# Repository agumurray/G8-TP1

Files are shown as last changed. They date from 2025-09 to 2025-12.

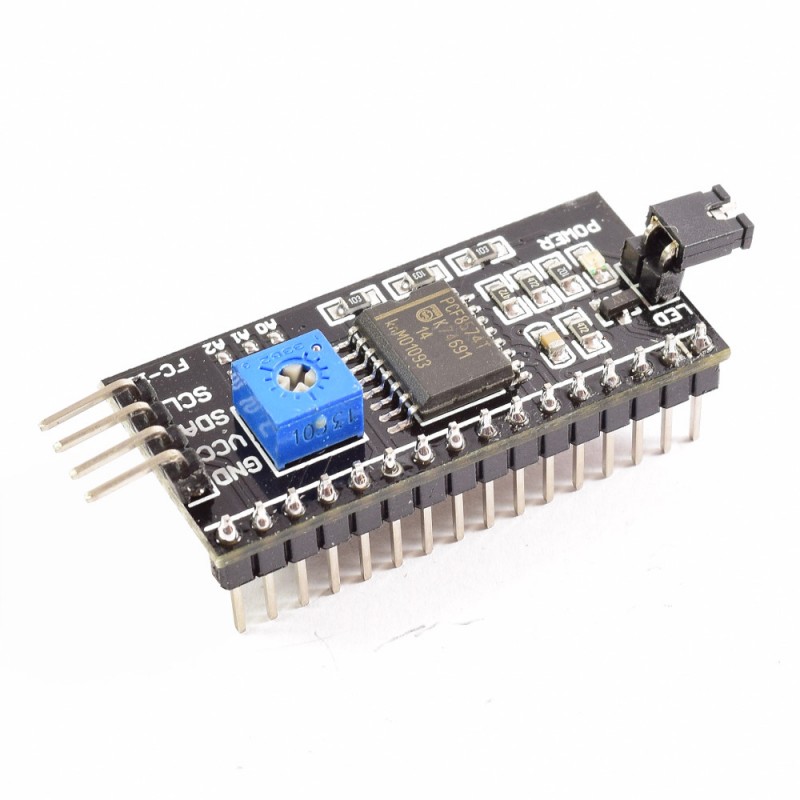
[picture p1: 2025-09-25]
firmware_v3/test/test_hcsr04/sapi/lcd/lcd_i2c/I2C expander PCF8574/modulo-adaptador-lcd-a-i2c_PCF8574.jpg

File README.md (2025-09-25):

# TdP-Grupo8-2025

**Robot resolutor de laberintos con EDU-CIAA**

Este proyecto consiste en el diseño y construcción de un robot móvil capaz de resolver laberintos físicos con paredes de manera autónoma. El sistema utiliza como controlador principal la **EDU-CIAA**, que gestiona los sensores y motores, y ejecuta algoritmos de navegación para alcanzar la salida sin necesidad de un mapa previo.

## Características principales

* Exploración autónoma de laberintos físicos.
* Algoritmos de resolución basados en estrategias clásicas (wall-following, Pledge, Trémaux).
* Plataforma móvil con dos motores DC controlados mediante un puente H L298N.
* Sensores ultrasónicos para la detección de paredes y obstáculos.
* Posibilidad de extender funcionalidades con:

  * Telemetría mediante ESP32 e interfaz web.
  * Algoritmos de búsqueda óptima (Flood Fill, A*).
  * Sensores adicionales como giroscopio para corrección de trayectoria.

## Tecnologías utilizadas

* **Hardware:**

  * EDU-CIAA (controlador central).
  * Motores DC con puente H L298N.
  * Sensores ultrasónicos HC-SR04.
  * Batería y sistema de alimentación dedicado.
  * (Opcional) ESP32 para telemetría y giroscopio.

* **Software:**

  * Lenguaje C para firmware en la EDU-CIAA.
  * Algoritmos de filtrado de señales y resolución de laberintos.
  * (Opcional) HTML/CSS/JavaScript para interfaz web de monitoreo.

## Objetivos

* **General:** Desarrollar un robot controlado por EDU-CIAA capaz de explorar físicamente un laberinto con paredes y alcanzar la salida mediante estrategias de navegación autónoma.

* **Primarios:**

  1. Diseñar la plataforma mecánica y de potencia (chasis, ruedas, transmisión, alimentación).
  2. Integrar sensado frontal para detección de paredes/obstáculos.
  3. Implementar un algoritmo de resolución de laberintos con información local.
  4. Validar el funcionamiento en laberintos de prueba con métricas definidas.

* **Secundarios:**

  1. Incorporar una interfaz web para recolectar telemetría.
  2. Implementar algoritmos de búsqueda óptima.
  3. Integrar un sensor giroscópico para corrección de maniobras.

## Integrantes

Este proyecto fue desarrollado por el **Grupo 8** en el marco de la materia **Taller de Proyecto I** en la Facultad de Ingeniería de la UNLP:

* Cabral Ramiro Nicolas
* Murray Agustín
* González Juan
* Mendoza Tomás

---

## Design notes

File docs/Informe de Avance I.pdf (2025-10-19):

Informe de Avance I - Taller de Proyecto I

Robot resolutor de laberintos con EDU-CIAA

Grupo 8

Cabral Ramiro, Murray Agustin, Gonzalez Juan, Mendoza Tomas

Facultad de Ingeniería - UNLP

Introducción

El presente proyecto tiene como objetivo el desarrollo de un robot móvil autónomo capaz de

resolver laberintos. El sistema se basa en la placa de desarrollo EDU-CIAA-NXP, la cual

cumple el rol de unidad de control central. El robot se desplazará mediante dos motores de

corriente continua controlados a través de un puente H L298N, y contará con tres sensores

ultrasónicos HC-SR04 para la detección de obstáculos.

El algoritmo principal de navegación estará orientado a la resolución de laberintos, utilizando

estrategias como el “Wall Follower” o variantes más avanzadas. Como objetivo secundario, se

busca que el robot pueda comunicar información a la PC vía UART, lo que permitirá un

monitoreo en tiempo real y facilitará las tareas de depuración.

Este proyecto representa una oportunidad para aplicar conocimientos adquiridos en control,

programación embebida, electrónica digital y analógica, así como en integración de sistemas.

Objetivos del proyecto

Objetivos principales

- Diseñar la plataforma mecánica y de potencia (chasis, ruedas, alimentación) adecuada

para pruebas en laberintos.

- Integrar sensores ultrasónicos para detección de obstáculos y paredes.
- Implementar un algoritmo de resolución de laberintos autónomo (p. ej. Wall Follower).
- Implementar rutinas de control de motores basadas en tracción diferencial (PWM +

puente H).

- Establecer protocolos de prueba y métricas de éxito.

Objetivos secundarios

- Implementar comunicación UART con PC para telemetría
- Evaluar la incorporación de algoritmos más complejos (Flood Fill, A*).
- Analizar la posibilidad de integrar sensores adicionales (ej. giroscopio).

Análisis de requerimientos

Requerimientos funcionales - Hardware

- El sistema debe usar la EDU-CIAA como controlador central.
- El robot debe disponer de dos motores DC controlados por un driver L298N, capaces de

ejecutar avance, retroceso y giros en el lugar.

- Debe incluir tres sensores ultrasónicos HC-SR04 (1 frontal, 2 laterales).
- Fuente de alimentación autónoma con batería recargable de 7.4 V.
- Regulación de nivel lógico en señales de entrada (ECHO de sensores: de 5 V a 3.3 V).

Requerimientos funcionales - Software

- Lectura confiable de los sensores ultrasónicos y conversión a distancia en cm.
- Filtrado de ruido en lecturas (media móvil).
- Rutinas de movimiento: avance recto, giro en sitio, retroceso y parada.
- Algoritmo de resolución de laberintos (mínimo Wall Follower).
- Comunicación UART con PC para debug.

Requerimientos no funcionales

- Código modular, documentado y versionado en Git.
- Seguridad eléctrica mínima: protección contra inversión de polaridad, separación de

alimentación motores/lógica.

- Facilidad de prueba: modos de calibración de sensores y motores.
- Cumplir con los hitos de entrega fijados por la cátedra:
- Informe de Avance I: 2 de Octubre de 2025.
- Informe de Avance II: 3 de Noviembre de 2025
- Informe final: 18 de diciembre de 2025

Diseño de hardware

Componentes principales

- EDU-CIAA-NXP: placa de desarrollo basada en el microcontrolador ARM Cortex-M4

LPC4337. Permite gestionar periféricos, manejar interrupciones y ejecutar el algoritmo

de resolución.

- Sensores ultrasónicos HC-SR04 (x3): permiten medir distancias en distintas direcciones

(frontal y laterales). Operan con señal de disparo (Trigger) y eco (Echo).

- Driver de motores L298N: puente H doble que permite controlar la velocidad y sentido

de giro de dos motores DC.

- Motores DC (x2): utilizados para la tracción diferencial. Su control se logra mediante

PWM aplicado al L298N.

- Batería 18650 Li-ion 2600 mAh (x2): fuente de energía principal del sistema. Permite

portabilidad y autonomía suficiente para pruebas de campo.

- Divisores resistivos: Se utilizaran para llevar las señales ECHO de los sensores de 5V a

3.3V, que es el nivel que soportan las entradas de la placa.

- Estructura mecánica: chasis liviano con dos ruedas motrices y una rueda loca

estabilizadora.

Interfaces eléctricas

Elemento | Tension de operacion | Corriente típica | Corriente máxima
EDU-CIAA-NXP | 5V | 150mA | 300mA
HC-SR04 | 5V | 15mA | 30mA
L298N (control) | 5V | 20mA | 50mA
Motor DC | 7.4V | 300mA | 1A

Para el correcto funcionamiento del sistema se seleccionó como fuente de alimentación dos

baterías recargables 18650 de 3.7 V y 2600 mAh conectadas en serie, lo que proporciona una

tensión nominal de 7.4 V y un máximo de 8.4 V al estar completamente cargadas. Esta elección

permite disponer de una fuente portátil, liviana y con suficiente capacidad energética para

sostener el funcionamiento del robot durante las pruebas.

Los cálculos de consumo realizados muestran que, en condiciones típicas de operación, el

sistema demanda aproximadamente 0.77 A desde la batería, lo que se traduce en una autonomía

teórica de alrededor de 3.3 horas. Considerando pérdidas, variaciones en la eficiencia y picos de corriente de arranque, se estima una duración práctica de entre 2.8 y 3.2 horas, lo cual resulta

adecuado para el uso en un prototipo experimental.

En situaciones de arranque o bloqueo de los motores, el consumo puede alcanzar picos cercanos

a 2.2 A, reduciendo la autonomía a aproximadamente 1.2 horas si esta condición extrema se

mantuviera de forma continua. Sin embargo, en la práctica estos picos son breves y no

comprometen la estabilidad general del sistema.

El driver L298N introduce una caída de tensión de aproximadamente 2 V en los canales de

potencia, lo que implica cierta disipación térmica. Por esta razón, se recomienda el uso de un

pequeño disipador en el integrado y evitar condiciones de motor bloqueado por tiempos

prolongados. Aun así, el componente resulta suficiente para manejar los dos motores DC del

chasis en la etapa de desarrollo.

El mismo módulo L298N dispone de una salida regulada de 5 V, la cual se utiliza para alimentar

directamente la placa EDU-CIAA y los sensores ultrasónicos. De este modo, se simplifica la

distribución de energía y se evita la necesidad de un regulador adicional.

Finalmente, las señales de retorno ECHO de los sensores HC-SR04 requieren adaptación de

nivel, dado que la EDU-CIAA admite un máximo de 3.3 V en sus entradas. Para ello se

implementan divisores resistivos formados por una resistencia de 10 kΩ (conectada a la salida

ECHO) y otra de 20 kΩ a masa. El cálculo de la tensión de salida es:

V | , donde | , | y
in = V
out

·

R2
R1 + R2 | V

in = 5V R1 = 10 kΩ R2 = 20 kΩ

Entonces, V
out ≃ 3. 33V

Lista de materiales (BOM con precios ML)

Componente | Cant. | Precio unitario (ARS) | Total (ARS)
EDU-CIAA-NXP | 1 | 90.000 | 90.000
HC-SR04 | 3 | 3.500 | 10.500
L298N | 1 | 5.500 | 5.500
Kit auto arduino (incluye chasis, ruedas y motores) | 1 | 25.000 | 25.000
Baterías 18650 Motoma 2600 mAh | 2 | 3.000 | 6.000
Misceláneos (cables, divisores resistivos, soportes) | - | 5.000 | 5.000

Circuito esquemático

En la siguiente figura se presenta el diseño esquemático en KiCad, donde se observa la

interconexión entre la EDU-CIAA, los tres sensores ultrasónicos, el driver de motores L298N y

los motores DC.

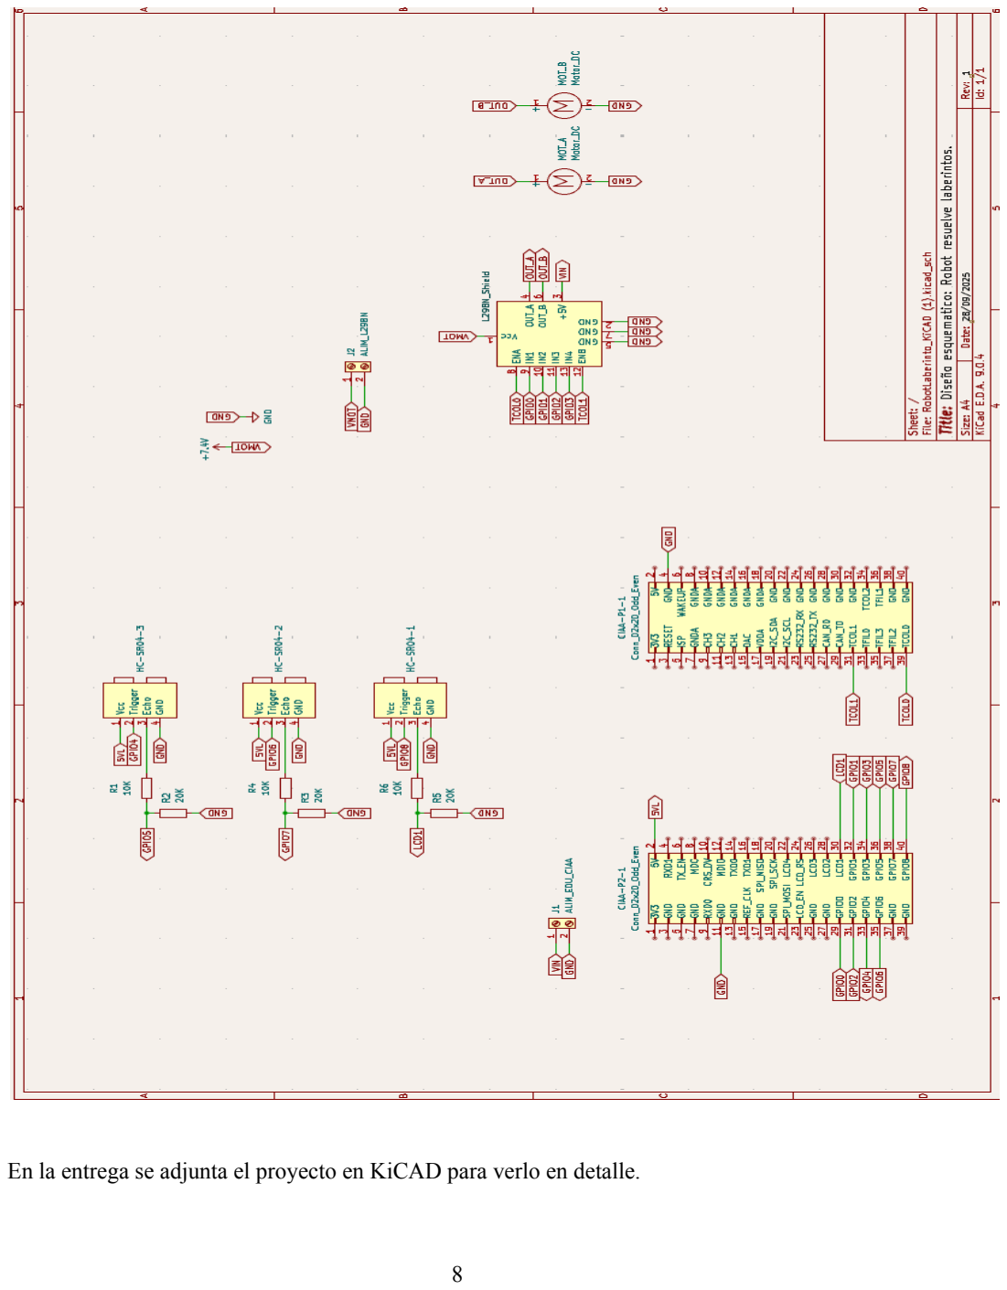
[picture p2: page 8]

En la entrega se adjunta el proyecto en KiCAD para verlo en detalle.

Diseño del firmware

El desarrollo del firmware para el robot resolutor de laberintos se plantea bajo una arquitectura

modular, con separación en capas bien definidas, lo que permitirá mayor claridad en el

mantenimiento y la depuración del sistema. La EDU-CIAA-NXP, basada en el microcontrolador

LPC4337, será la encargada de ejecutar todas las rutinas de control, sensado y comunicación.

Arquitectura del firmware

El firmware se organiza en tres capas principales:

1. Capa de Drivers (Bajo nivel):
- Configuración de periféricos básicos de la EDU-CIAA (GPIO, PWM, UART,

timers).

- Rutinas para el disparo y lectura de los sensores ultrasónicos HC-SR04.
- Control de las señales de entrada al L298N (Enable y direccionales).
- Conversión de las lecturas de tiempo de vuelo a distancia en centímetros.
2. Capa Intermedia (Middleware / Librerías):

- Implementación de rutinas de filtrado de señales (ej. media móvil de N muestras)

para minimizar errores en las lecturas ultrasónicas.

- Módulos de control de movimiento de alto nivel: avance, retroceso, giro a

derecha, giro a izquierda, detener.

- Gestión de comunicación UART (envío de telemetría y recepción de comandos de

prueba desde PC).

3. Capa de Aplicación (Algoritmo de navegación):
- Implementación del algoritmo Wall Follower como solución mínima para la

resolución del laberinto.

- Integración de las decisiones del algoritmo con las rutinas de movimiento.
- Generación de información de estado y eventos enviados a la PC para depuración.

Este diseño modular permitirá que futuros cambios en sensores, drivers o algoritmos no afecten

la totalidad del sistema.

Esquema de funcionamiento

El ciclo principal del programa está basado en un bucle infinito con atención periódica a

interrupciones de temporizadores.

- Los temporizadores gestionan la generación de señales PWM para los motores.
- Una interrupción periódica se encarga de iniciar las mediciones ultrasónicas de forma

secuencial (disparando cada sensor en turnos).

- El bucle principal lee los resultados procesados, aplica el algoritmo de decisión y

actualiza el estado de los motores.

- Paralelamente, se ejecutan rutinas de transmisión UART para enviar los datos a la PC.

Diagrama de flujo simplificado:

1. Inicializar periféricos (PWM, GPIO, UART, timers).
2. Iniciar medición de sensores ultrasónicos en forma cíclica.
3. Filtrar y almacenar las lecturas de distancia.

4. Evaluar condiciones del laberinto según el algoritmo Wall Follower:
- Si hay camino libre al frente, avanzar.
- Si hay pared a la izquierda, continuar recto.
- Si no hay pared a la izquierda, girar en esa dirección.
- Si la trayectoria está bloqueada, girar a la derecha o retroceder.
5. Enviar datos de estado y distancias por UART.
6. Repetir.

Cronograma

Link al cronograma. (https://docs.google.com/spreadsheets/d/1fumWjYeI3rMNOMrfwoXf-empmanw7tX2/edit?gid=771373370)

División de tareas

Juan | Ramiro | Agustin | Tomas
Algoritmo de movimiento del robot (avanzar, girar) | Algoritmo de resolución de laberintos | Armado del circuito de alimentación e interconexión | Montaje del equipo
Armado de laberintos | Diseño del circuito esquemático en KiCAD | Lógica de sensado | Diseño del circuito esquemático en KiCAD
| Integración de esp32 para telemetría (secundario) | Integración de giroscopio (secundario) | Algoritmo de recolección de datos (secundario

Bibliografía

- Proyecto CIAA: https://www.proyecto-ciaa.com.ar/
- HC-SR04 datasheet: https://cdn.sparkfun.com/datasheets/Sensors/Proximity/HCSR04.pdf
- L298N datasheet:

https://drive.google.com/drive/u/0/folders/1ENpeQHSaa5TVw6c3gilW9JXR4ox_CZ4J

- Algoritmos de resolución de laberintos:

https://en.wikipedia.org/wiki/Maze-solving_algorithm

- KiCAD EDA: https://www.kicad.org/

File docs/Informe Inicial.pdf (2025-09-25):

Informe Inicial - Taller de Proyecto I

Robot resolutor de laberintos con EDU-CIAA

Grupo 8

Cabral Ramiro, Murray Agustin, Gonzalez Juan, Mendoza Tomas

Facultad de Ingeniería - UNLP

Introducción

Este proyecto propone diseñar y construir un robot móvil que resuelve laberintos físicos con

paredes utilizando como controlador principal la EDU-CIAA (plataforma educativa basada en la

familia CIAA). La elección de EDU-CIAA está fijada por la cátedra y orienta la implementación

del firmware y el acceso a E/S y periféricos. [1]

El objetivo en esta etapa inicial es definir el alcance físico y funcional del prototipo mínimo

viable y los criterios de validación. La intención es comenzar con una plataforma de tracción

simple, sensado para detección de paredes, y un algoritmo que permita al robot, con información

local (sin mapa previo), encontrar la salida del laberinto; en una segunda fase se podrá evaluar la

inclusión de telemetría y una interfaz móvil/web para registro y visualización de estadísticas.

Objetivos

Objetivo general: Desarrollar un robot, controlado por la EDU-CIAA, capaz de explorar

físicamente un laberinto con paredes y alcanzar la salida mediante estrategias de navegación

autónoma.

- Objetivos primarios:
1. Diseñar la plataforma mecánica y de potencia (chasis, ruedas, transmisión,

alimentación) adecuada para pruebas en un laberinto con paredes.

2. Integrar sensado frontal para detección de paredes/obstáculos y un módulo de

control que permita maniobrar (avanzar, girar, detener).

3. Implementar un algoritmo de resolución de laberintos apropiado para operar con

información local (p.ej. wall-following, Pledge o Trémaux) y validar su

funcionamiento en al menos un conjunto de laberintos de prueba. [2]

4. Definir protocolos de prueba, métricas de éxito y documentación mínima para

replicar los ensayos.

- Objetivos secundarios:
1. Implementar una interfaz web para recolectar telemetría y análisis del

funcionamiento del robot, utilizando un microcontrolador como el ESP-32 o

similar.

2. Implementar un algoritmo de búsqueda óptima para la resolución del laberinto,

como el Flood Fill o el A*.

3. Incorporar un sensor giroscópico que proporcione mediciones de orientación y

rotación angular, con el objetivo de corregir desviaciones durante las maniobras.

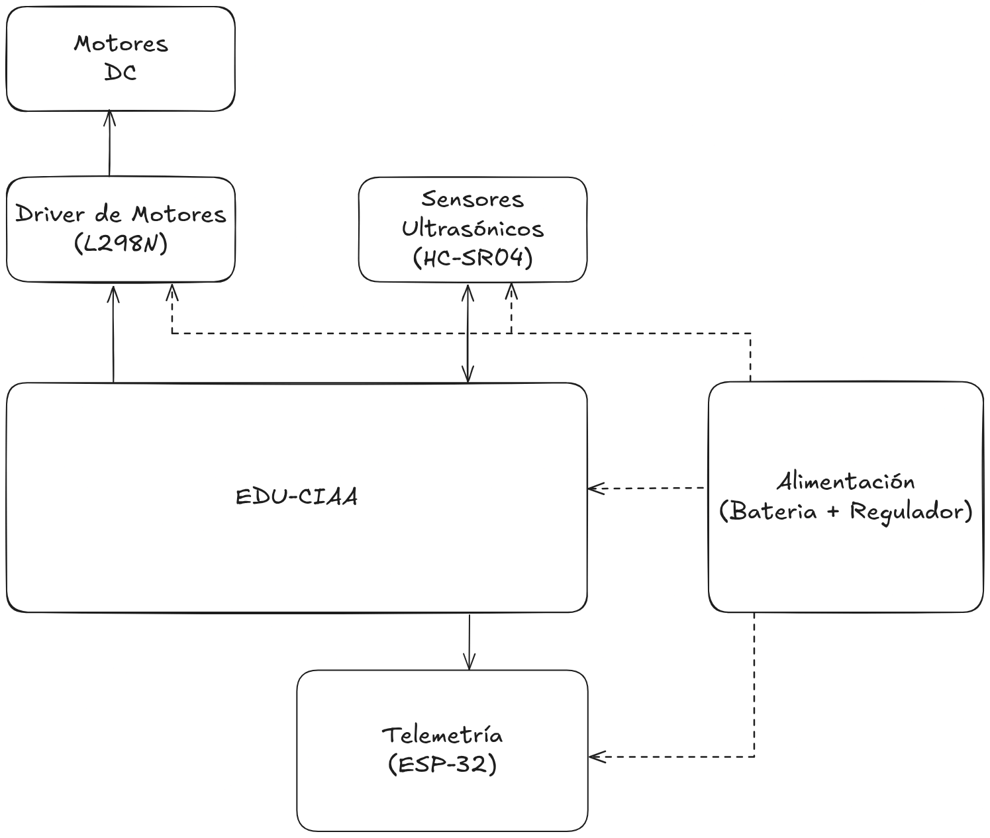
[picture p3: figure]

Figura 1: Diagrama en bloques.

En la Fig. 1 se presenta el diagrama en bloques del robot, el cual consiste de la EDU-CIAA, la

cual recolecta datos de los sensores ultrasónicos, y en base a los datos recolectados y según un

algoritmo de resolución, acciona los motores para poder mover al robot. Los dos motores

utilizados son accionados mediante un Puente-H L298N. Adicionalmente, según lo aclarado en

los objetivos secundarios, eventualmente se puede incorporar un microcontrolador como el

ESP-32 o similar con el fin de recolectar telemetría y presentar información en una interfaz web.

Análisis de requerimientos

- Requerimientos funcionales - Hardware
1. El sistema debe usar la EDU-CIAA como controlador central (E/S digitales,

temporizadores, ADC, UART, entre otros).

2. El robot tendrá una plataforma con varias ruedas y al menos dos actuadores

(configuración a definir) capaz de controlar avance y giros.

3. Disponer de uno o más sensores de distancia/proximidad (basados en tiempo de

vuelo acústico o equivalente) ubicados en la parte frontal y, opcionalmente,

laterales, para detectar paredes.

4. Fuente de alimentación apropiada para electrónica y motores, con separación y

protecciones razonables.

- Requerimientos funcionales - Software
1. Lectura fiable de los sensores de distancia y conversión a unidades físicas (cm o
m) usando la relación tiempo-velocidad del sonido (Time-of-Flight). [3]
2. Filtrado básico de las lecturas (p.ej. media móvil o mediana) para reducir ruido y

rechazar lecturas aberrantes.

3. Rutinas de movimiento: avance controlado, giro en el lugar (90° u otros ángulos

definidos) y parada segura.

4. Algoritmo de toma de decisiones para resolver el laberinto.
- Requerimientos no funcionales
1. Código modular y documentado; control de versiones.

2. Seguridad eléctrica mínima: separación de fuentes, protección contra inversión de

polaridad y cortes seguros en caso de fallo.

3. Facilidad de pruebas: puntos de prueba para sensores y actuadores, y modo

“calibración” para ajustar parámetros.

Cronograma preliminar

Se adjunta el link: Cronograma.xlsx (https://docs.google.com/spreadsheets/d/1fumWjYeI3rMNOMrfwoXf-empmanw7tX2/edit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)

División de tareas del grupo

Se realiza una primera división estimativa. La misma está sujeta a cambios ya que durante el

proceso de desarrollo, es posible que aparezcan nuevos problemas y/o retos a resolver.

Juan | Ramiro | Agustin | Tomas
Algoritmo de movimiento del robot (avanzar, girar) | Algoritmo de resolución de laberintos | Armado del circuito de alimentación e interconexión | Montaje del equipo
Armado de laberintos | Integración de esp32 para telemetría (secundario) | Lógica de sensado | Algoritmo de recolección de datos (secundario)
| | Integración de giroscopio (secundario)

Bibliografía

1. Proyecto CIAA (https://www.proyecto-ciaa.com.ar/index_comprar_educiaanxp_en.html)
2. Algoritmo de resolución de laberintos (https://en.wikipedia.org/wiki/Maze-solving_algorithm)

3. Funcionamiento de sensores ultrasonido (https://www.ti.com/lit/pdf/slaa907)

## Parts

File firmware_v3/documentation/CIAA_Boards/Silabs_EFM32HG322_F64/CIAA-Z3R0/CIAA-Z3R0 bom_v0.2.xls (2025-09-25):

Reference | Quantity | Value | Footprint | Part number | digikey part number
C12 | 1 | 4.7u | Capacitor 0603 | CC0603KRX5R7BB475 | 311-1785-1-ND
C2 C3 C4 C5 C6 | 5 | 100n | Capacitor 0603 | CC0603KRX7R7BB104 | 311-1088-1-ND
C8 | 1 | 10u | Capacitor 0603 | GRM188R61C106KAALD | 490-10728-1-ND
C1 C10 C11 C7 C9 | 5 | 1u | Capacitor 0603 | CC0603KRX7R7BB105 | 311-1446-1-ND
D1 D3 | 2 | LED GREEN | LED 0805 | LTST-C170GKT | 160-1179-1-ND
D2 | 1 | PMEG2005CT | SOT-23-3 | PMEG2005CT,215 | 1727-5188-1-ND
D4 | 1 | SD0603S040S0R2 | Diode 0603 | SD0603S040S0R2 | 478-7798-1-ND
U1 | 1 | EFM32HG-48LQFP | LQFP-48 7x7mm Pitch 0.5mm | EFM32HG322F64G-B-QFP48 | 336-3835-ND
U2 | 1 | SPX3819M5-L-3-3 | SOT-23-5 | SPX3819M5-L-3-3/TR | 1016-1873-1-ND
U3 | 1 | USBLC6-2 | SOT-23-6 | USBLC6-2SC6 | 497-5235-1-ND
SW1 SW2 | 2 | Switch EVQ-PE105K | Switch SPST-NO 6mm x 3.5mm | EVQ-PE105K | P13594SCT-ND
J3 | 1 | USB Micro-B | USB_Micro-B_Molex_47346-0001 | Molex 473460001 | WM17141CT-ND
J4 | 1 | Header SMD 2x2 Pitch 2.54mm | Pin Header 2x2 Pitch 2.54mm SMD | M20-8760242 | 952-3254-ND
R1 R2 | 2 | 15R | Resistor 0603 | RC0603JR-0715RL | 311-15GRCT-ND
R3 R4 R5 R6 | 4 | 1K | Resistor 0603 | RC0603JR-0710KL | 311-10KGRCT-ND

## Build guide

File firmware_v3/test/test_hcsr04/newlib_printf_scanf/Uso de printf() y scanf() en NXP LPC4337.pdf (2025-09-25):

# Uso de printf() y scanf() en el microcontrolador NXP LPC4337

# Biblioteca newlib, printf() y scanf() completas o reducidas

La biblioteca estándar de C llamada newlib, que incluye el compilador arm-none-eabi del NXP LPC4337 (el microcontrolador que tiene al EDU-CIAA-NXP o la CIAA-NXP) permite utilizar printf() y scanf() con el microcontrolador.

La biblioteca newlib permite ser compilada en 2 versiones. Una versión completa y una versión reducida nombrada newlib nano.

Si se utiliza newlib nano printf() y scanf() no permiten imprimir o recibir valores en punto flotante (float).

Para desactivar newlib nano y que compila la new lib completa en la carpeta app del proyecto, el archivo config.mk poner:

USE_NANO=n

Por defecto viene en y (que si use nano).

De esta manera podemos poner en un programa:

printf( "Pi vale aproximadamente %f\n", 3.14 );

scanf() y printf() utilizan la UART2 del microcontrolador (UART_USB en la sAPI) como entrada/salida estándar por lo que no se debería reconfigurar la UART2, la está configurada por defecto a 115200 baudios. Esto se hace en el startup del microcontroaldor.

Entonces un programa básico que utilice printf() puede ser simplemente:

#include "sapi.h" // <= Biblioteca sAPI, o alternativamente puede

| // usarse board.h que incluye LPCOpen
int main( void )
{
printf( "Pi vale aproximadamente %f\n", 3.14 ); while( TRUE );
return 0;
}

NOTA:

Si usan printf() en un microcontrolador van a notar que no imprime directamente (envía directo a la UART) si no que lo hace a través de un buffer el cual se envía a la salida estándar, en nuestro caso la UART.

En un programa en la PC si no hay \n este buffer se envía a la salida estándar cuando se llama a la función fflush(), la cual por ejemplo se llama cuando termina el programa.

En embebidos el programa no termina nunca (por el while(1)), entonces hay que forzar el fflush de 2 formas:

1. Llamando a la función fflush():

fflush(stdout);

2. Con \n dentro del texto de printf()

printf( "Hola\n" );

# Uso de memorias del microcontrolador

Se puede probar compilar el mismo programa con la opción USE_NANO en "y" y también en "n" y observar la diferencia de ocupación de memorias.

### Con newlib nano

text | data | bss | dec | hex filename
11460 | 300 | 76 | 11836 | 2e3c app/out/app.elf

En este caso printf() no imprime los valores float %f, pero no da errores, simplemente los ignora.

### Con newlib completa

text | data | bss | dec | hex filename
28992 | 2676 | 152 | 31820 | 7c4c app/out/app.elf

En este caso printf() funciona con todas sus características.

Para comprender esos números, todos están en bytes y representan:

- text - contiene el código compilado y datos de sólo lectura (read-only) de la aplicación (el valor de bytes está en decimal).
- data - shows the read-write data in your application (el valor de bytes está en decimal).
- bss - Muestra los datos inicializados con 0 ('bss' y 'common') en la aplicación (el valor de bytes está en decimal).
- dec - Total = 'text' + 'data' + 'bss' (el valor de bytes está en decimal).
- hex - El valor de bytes en hexadecimal equivalente al de 'dec'.

Esto típicamente se interpreta como:

- Consumo de FLASH de la aplicación equivale a text + data.
- Consumo de RAM de la aplicación equivale a data + bss.

Más información en: http://www.support.code-red-tech.com/CodeRedWiki/FlashRamSize

Como puede observarse, newlib completa ocupa muchos más recursos.

# Uso de printf() y scanf()

## printf()

Las funciones de la familia printf producen una salida de acuerdo a format como se describe abajo. Printf y vprintf escriben su salida a stdout, el flujo de salida estándar. fprintf y vfprintf escriben su salida al stream de salida dado. sprintf, snprintf, vsprintf y vsnprintf escriben a una cadena de caracteres str.

### Prototipo o declaración

int printf( const char *format, ... );

### Ejemplos

printf("Strings:\n");
const char* s = "Hello";
printf("\t.%10s.\n\t.%-10s.\n\t.%*s.\n", s, s, 10, s);

printf("Characters:\t%c %%\n", 65);

printf("Integers\n");
printf("Decimal:\t%i %d %.6i %i %.0i %+i %u\n",1,2,3,0,0,4,-1); printf("Hexadecimal:\t%x %x %X %#x\n", 5, 10, 10, 6); printf("Octal:\t%o %#o %#o\n", 10, 10, 4);

printf("Floating point\n");
printf("Rounding:\t%f %.0f %.32f\n", 1.5, 1.5, 1.3); printf("Padding:\t%05.2f %.2f %5.2f\n", 1.5, 1.5, 1.5); printf("Scientific:\t%E %e\n", 1.5, 1.5); printf("Hexadecimal:\t%a %A\n", 1.5, 1.5);

### Los caracteres % (especificaciones de conversión)

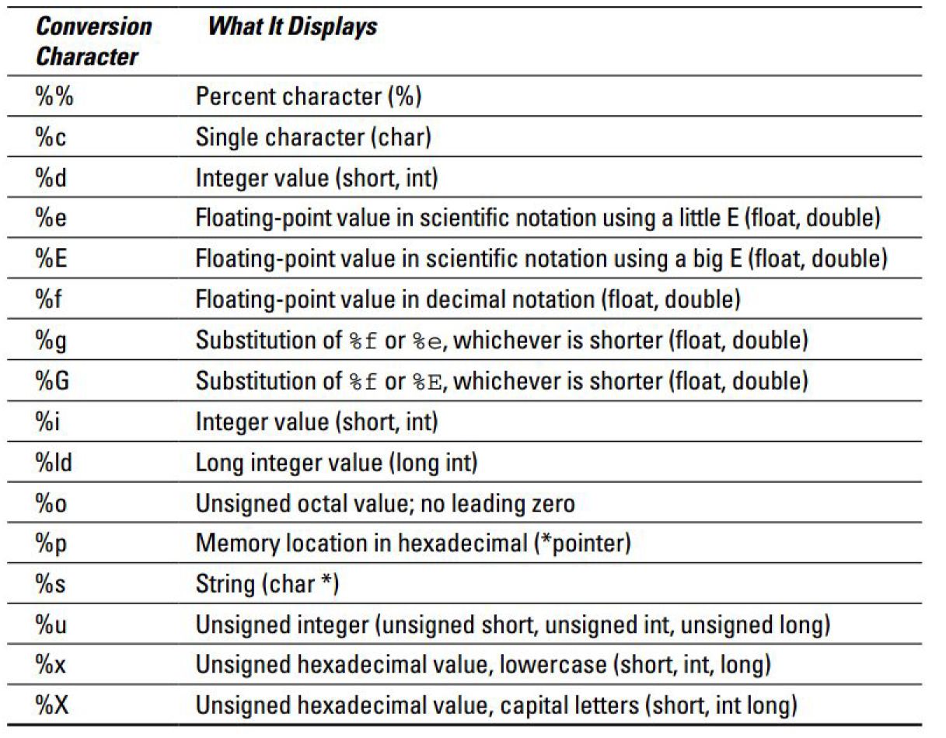
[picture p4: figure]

### Más información

- http://es.tldp.org/Paginas-manual/man-pages-es-1.28/man3/printf.3.html
- https://es.cppreference.com/w/c/io/fprintf

## scanf()

La familia scanf de funciones busca en la entrada según un formato como se describe más adelante. Este formato puede contener especificadores de conversión; los resultados de tales conversiones, si las hay, se guardan donde apunten los argumentos punteros. La
función scanf | lee la entrada del flujo de entrada estándar stdin, fscanf | lee su entrada del
puntero a FILE flujo, y sscanf | lee su entrada de la cadena de caracteres a la que apunte str.

### Prototipo o declaración

int scanf( const char *format, ... );

### Ejemplo

char text[50];
printf( "Ingrese un texto y presione enter:\r\n" ); scanf( "%s", text );
printf( "El texto ingresado es: %s\r\n", text );

### Los carcateres % (especificaciones de conversión)

%c para indicar entrada de un caracter
%d para indicar entrada de un entero
%f para indicar entrada de un flotante
%s para indicar entrada de un string

### Sugerencias para el uso de scanf()

- Antes de usar scanf, imprimir con printf() indicando al usuario qué tipo de dato o información debe ingresar.
- Ingresar de a un dato por vez. Será mejor que cada llamado a scanf() sea para ingresar un dato, evitar el ingreso múltiple.
- Para ingresar texto, indicar el máximo de caracteres que scanf() debe aceptar, así no almacena en zonas inapropiadas.

### Más información

- http://es.tldp.org/Paginas-manual/man-pages-es-1.28/man3/scanf.3.html
- https://es.cppreference.com/w/c/io/fscanf

# Ejemplo con scanf() y printf()

#include "sapi.h" // <= Biblioteca sAPI, o alternativamente puede // usarse board.h que incluye LPCOpen

// La UART_USB se inicializa en el startup del microcontrolador a // 115200 baudios para salida y entrada estandar.

// Recordar en config.mk poner USE_NANO=n (usar newlib completa // en lugar de newlib nano) para tener soporte de flotantes en // printf(), sin embargo, esto causa que el programa ocupe MUCHA // mas RAM y FLASH.

int main( void )
{
printf( "Pi vale aproximadamente %f\r\n", 3.14 );

char text[50];
int num;

printf( "Ingrese un texto y presione enter:\r\n" ); scanf( "%s", text );
printf( "El texto ingresado es: %s\r\n", text );

printf( "Ingrese un numero y presione enter:\r\n" ); scanf( "%d", &num );
printf( "El numero ingresado es: %d\r\n", num );

while( TRUE );

return 0;
}

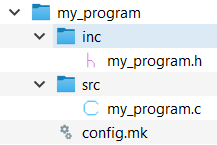
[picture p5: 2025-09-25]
firmware_v3/documentation/firmware/usage/select_program.png

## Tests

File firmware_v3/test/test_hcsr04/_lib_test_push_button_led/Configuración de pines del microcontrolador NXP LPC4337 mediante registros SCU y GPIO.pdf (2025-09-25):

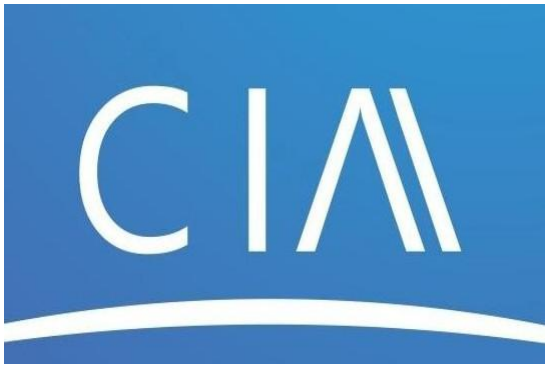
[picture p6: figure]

### Configuración de pines del microcontrolador NXP LPC4337 mediante registros SCU y GPIO

- Mg. Ing. Eric Pernia.
- Ing. Ian Olivieri

http://www.proyecto-ciaa.com.ar/

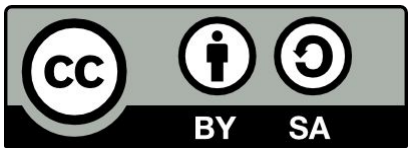
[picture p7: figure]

“Configuración de pines del microcontrolador NXP LPC4337 mediante registros SCU y GPIO” Por Esp. Ing. Eric Pernia e Ing. Ian Olivieri, se distribuye bajo una Licencia Creative Commons Atribución-CompartirIgual 4.0 Internacional. (http://creativecommons.org/licenses/by-sa/4.0/)

## Licencia

1. Diagrama en bloques de un pin.
2. Reconocer los pines del microcontrolador (MCU).
3. System Control Unit (SCU).
4. Registro SCU de configuración de pin SFSPN_M.
5. Configuración de pines para LED1 y TEC1.
6. SCU - Resumen de configuración para GPIO.
7. Registro de configuración de dirección de GPIO.

### 8. Configuración de dirección de pines para LED1 y

TEC1.

### 9. Funciones LPCOpen de GPIO para leer y escribir

pines.
10. Ejemplo Pulsador ---> LED.

## Temario

## Diagrama en bloques de un pin

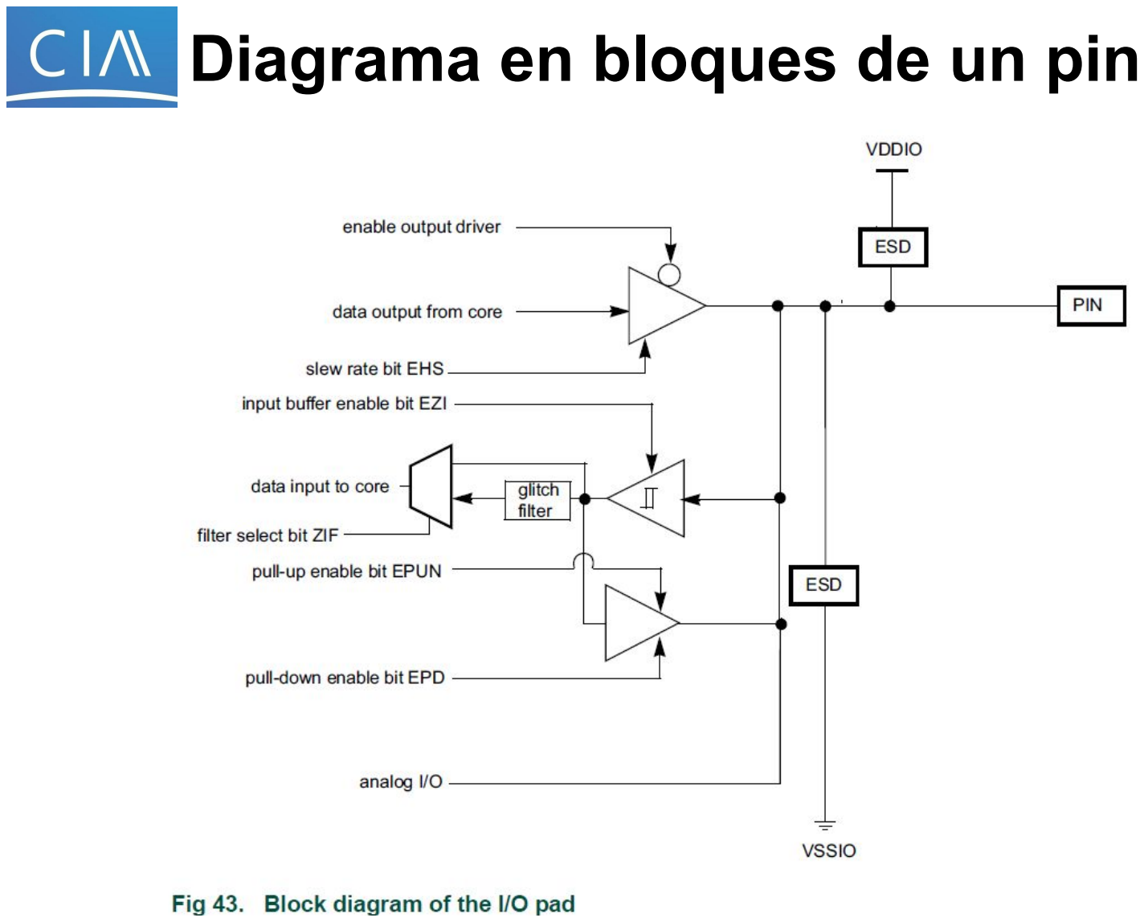
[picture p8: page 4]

Supongamos que queremos configurar en la EDU-CIAA-NXP los pines conectados a LED1 como salida digital y TEC1 como entrada digital.

Si miramos el archivo de asignación de pines de la EDU-CIAA-NXP veremos que:

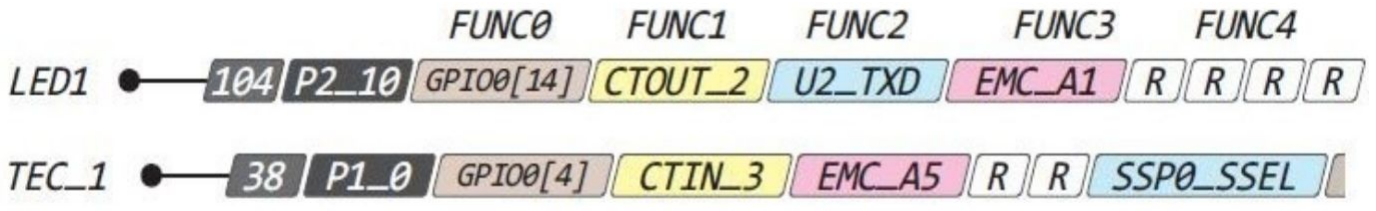
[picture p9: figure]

- El diodo LED, LED1, está conectado al Pin N° 104 del microcontrolador.
- El pulsador, TEC1, está conectado al Pin N° 38 del microcontrolador.

## Reconocer los pines del MCU

Para configurar un pin en el microcontrolador LPC4337 debemos conocer un subsistema encargado de la configuración de los pines el cual se llama System Control Unit (SCU).

Este se encarga de configurar a qué periférico interno se conecta un pin físico del chip (FUNC), además de otras configuraciones eléctricas de los mismos (pull resistors, glich filter, input buffer, etc.).

De esta forma, existe un registro de 32 bits asociado a cada pin donde configuramos al mismo nombrado:

SFSPN_M, con N número de port y M número de pin.

## System Control Unit (SCU)

Los parámetros port y pin para los registros SCU pueden ser obtenidos del manual de usuario del LPC4337 (página 242 de 1433). En esta presentación se utiliza como alternativa el documento asignación de pines de la EDU-CIAA-NXP que tiene un resumen de los pines de la plataforma.

Las funciones pueden ser FUNC0, FUNC1,... FUNC7 y su elección depende de como se requiera utilizar el pin.

## System Control Unit (SCU)

Si miramos nuevamente el archivo de asignación de pines de la EDU-CIAA-NXP veremos que:

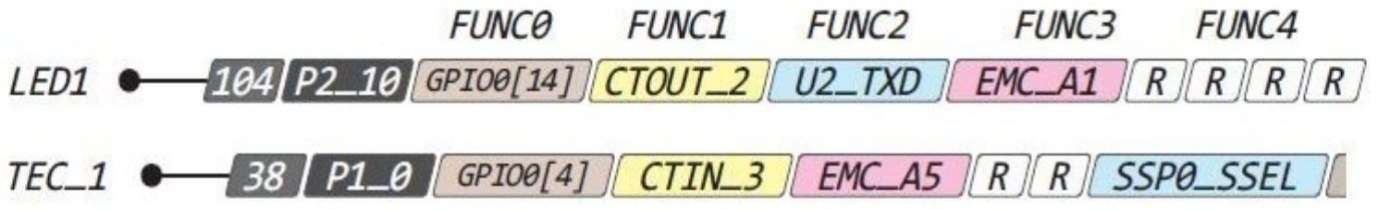
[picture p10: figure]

- LED1 (pin N° 104 del MCU) corresponde a P2_10 (Port = 2 y Pin = 10). Entonces se configura mediante el registro SFSP2_10.
- TEC1 (pin N° 104 del MCU) corresponde a P1_0 (Port = 1 y Pin = 0). Entonces se configura mediante el registro SFSP1_0.

También se ve que para estos pines físicos, la función que corresponde a GPIO es la FUNC0, que corresponde a los primeros bits de un cierto registro SFSPN_M como veremos a continuación.

## System Control Unit (SCU)

Registro SCU de configuración de pin SFSPN_M

Bits MODE del registro SFSPN_M para configurar a qué periférico interno se conecta un pin físico del MCU.

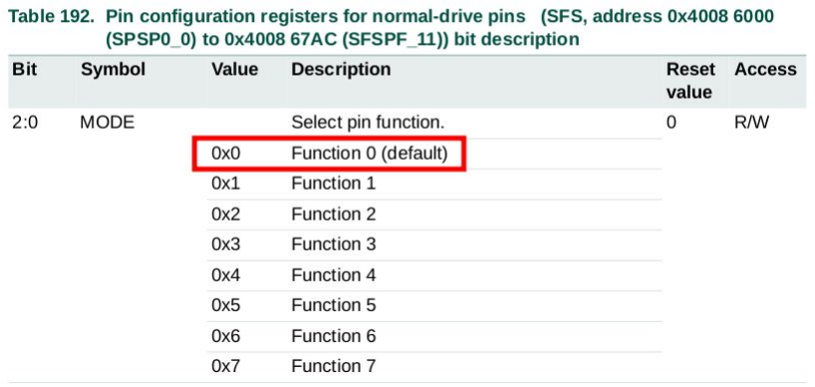
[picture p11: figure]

Registro SCU de configuración de pin SFSPN_M

Bits EPD y EPUN del registro SFSPN_M para configurar resistencias de Pull-down y Pull-Up conectadas a un pin físico del MCU.

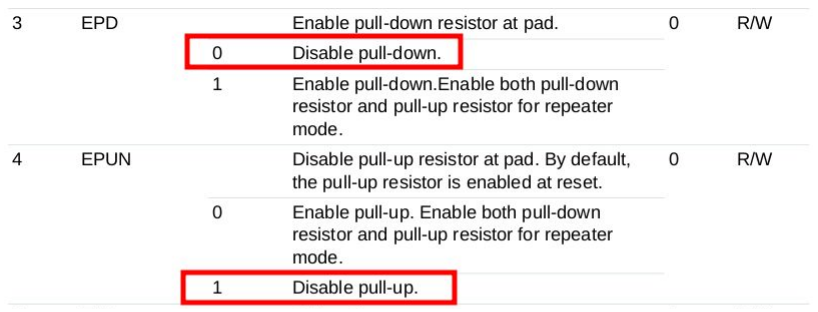
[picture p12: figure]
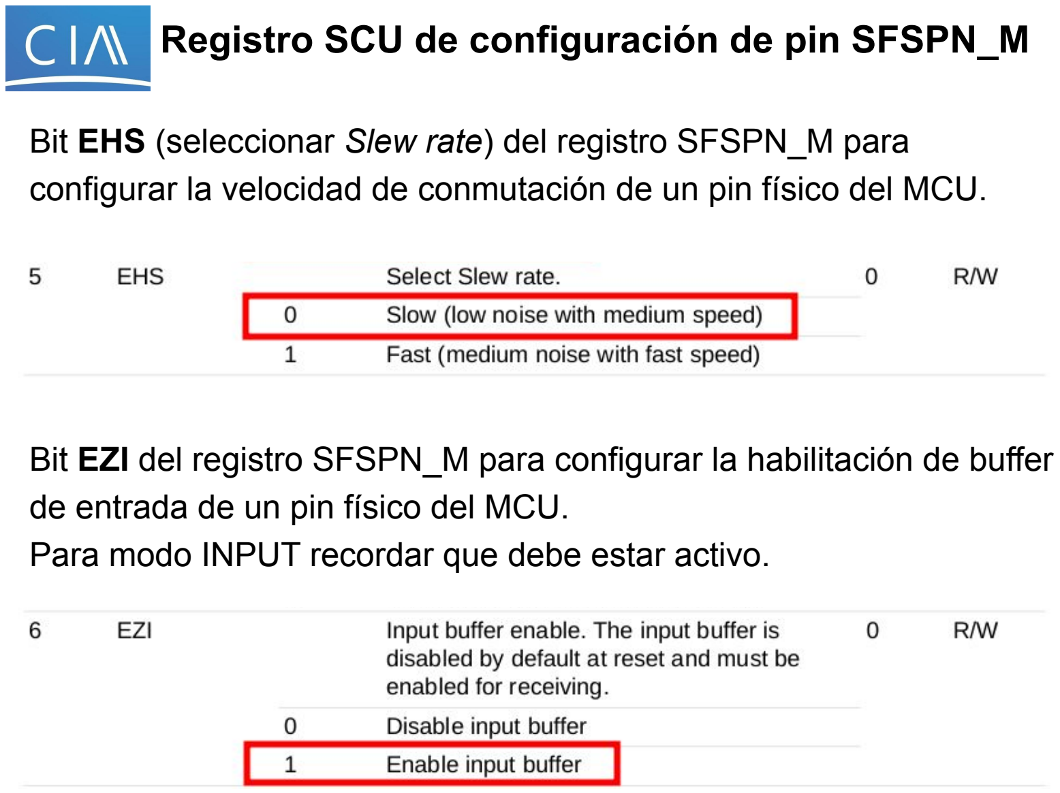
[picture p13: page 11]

Registro SCU de configuración de pin SFSPN_M

Bit EHS (seleccionar Slew rate) del registro SFSPN_M para configurar la velocidad de conmutación de un pin físico del MCU.

Bit EZI del registro SFSPN_M para configurar la habilitación de buffer de entrada de un pin físico del MCU.
Para modo INPUT recordar que debe estar activo.

Registro SCU de configuración de pin SFSPN_M

Bit ZIF del registro SFSPN_M para configurar la habilitación de filtro de ruido de entrada de un pin físico del MCU.

Las funciones de biblioteca que nos provee el fabricante (LPC Open) para realizar la configuración de SCU se encuentran en la biblioteca scu_18xx_43xx.h. En particular, utilizaremos la función:

void Chip_SCU_PinMux( uint8_t port, uint8_t pin, uint16_t mode, uint8_t func );

### Configuración de pines para LED1 y TEC1

A continuación veremos cómo se configuran ambos pines físicos (LED1 y TEC1) para que se conecten a sus respectivas funcionalidades de GPIO.

Diodo LED: | LED1 <---> P2_10, GPIO0[14], | FUNC0
Pulsador: | TEC1 <---> P1_0, | GPIO0[4], | FUNC0

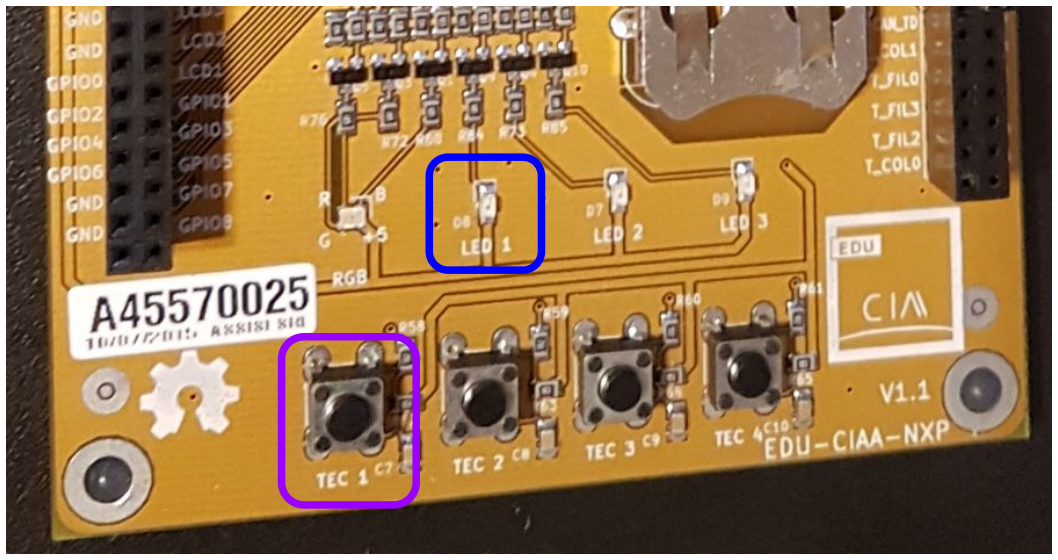
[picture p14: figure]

### Configuración de pines para LED1 y TEC1

Diodo LED: LED1 <---> P2_10, GPIO0[14], FUNC0

Configurar que el pin P2_10 se conecte internamente a GPIO0[14] mediante registro SFSP2_10:

Dirección del registro SFSP2_10 = SCU_BASE + SFSP2_10 (offset)
= 0x40086000 + 0x128 = 0x40086128

Valor de configuración a guardar en esa dirección =
= SCU_MODE_INACT | SCU_MODE_FUNC0
= (0x2 << 3) | 0x0 = 0x00000010

Usando LPCopen:

Chip_SCU_PinMux( 2, 10, SCU_MODE_INACT, SCU_MODE_FUNC0 );

### Configuración de pines para LED1 y TEC1

Pulsador: | TEC1 <---> P1_0, | GPIO0[4], | FUNC0

Configurar que el pin P1_0 se conecte internamente a GPIO0[4] mediante registro SFSP1_0:

Dirección del registro SFSP1_0 = SCU_BASE + SFSP1_0(offset)
= 0x40086000 + 0x080 = 0x40086080

Valor de configuración a guardar en esa dirección =
= SCU_MODE_INACT | SCU_MODE_INBUFF_EN | SCU_MODE_FUNC0
= (0x2 << 3) | (0x1 << 6) | 0x0 = 0x00000090

Usando LPCopen:

Chip_SCU_PinMux( 1, 0, SCU_MODE_INACT | SCU_MODE_INBUFF_EN,
SCU_MODE_FUNC0 );

En LPC4337 Para la funcionalidad de GPIO vamos a ver que se encuentran (si el pin soporta) en los modos FUNC0 o FUNC4. Además:

- Para el modo OUTPUT: SCU_MODE_INACT
- Para el modo INPUT (sin pull-up ni pull-down):
SCU_MODE_INACT | SCU_MODE_INBUFF_EN
- Para el modo INPUT_PULLUP (sólo con pull-up):
SCU_MODE_PULLUP | SCU_MODE_INBUFF_EN
- Para el modo INPUT_PULLDOWN (sólo con pull-down):
SCU_MODE_PULLDOWN | SCU_MODE_INBUFF_EN
- Para el modo INPUT_REPEATER (con pull-up y pull-down):
SCU_MODE_REPEATER | SCU_MODE_INBUFF_EN

Opcionalmente se puede agregar a todos: SCU_MODE_ZIF_DIS

Estos datos se encuentran en la página 413 del manual de usuario del LPC4337. Para más información referirse al capítulo 16 y 17 del manual de usuario del LPC4337

### SCU - Resumen de configuración para GPIO

Registro de configuración de dirección de GPIO

Los GPIO (General Purpose Input/Output) son las entradas y salidas digitales del microcontrolador. Los pines con funcionalidad de GPIO se agrupan en puertos y se numeran de la forma GPION[M]. Con N, número de puerto y M, número de pin en el puerto.

NOTA: Aquí, N y M no son los mismos que N y M para los registros de SCU.

Existe por cada puerto (puertos GPIO0 a GPIO7) un registro de dirección donde, mediante cada bit que lo compone, se configuran la dirección cada pin, es decir, si será entrada (0) o salida (1).

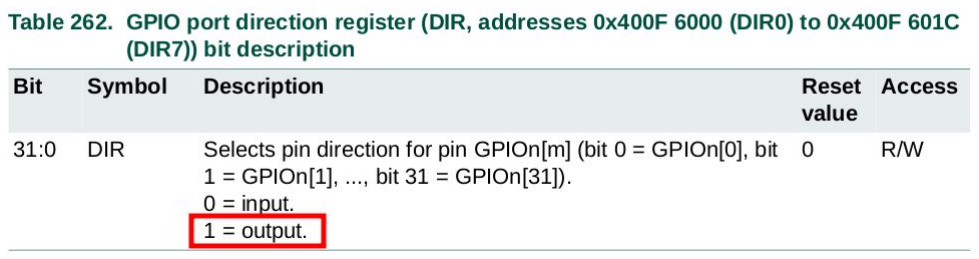
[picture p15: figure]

Las funciones de biblioteca que nos provee el fabricante (LPC Open) para realizar la configuración de GPIO se encuentran en la biblioteca gpio_18xx_43xx.h.

En particular, utilizaremos para configurar un pin como entrada o salida se utiliza la función:

void Chip_GPIO_SetDir( LPC_GPIO_T *pGPIO, uint8_t portNum,
uint32_t bitValue,
uint8_t out );

El primer parámetro de esta función (LPC_GPIO_T *pGPIO) equivale a LPC_GPIO_PORT para el LPC4337.

Aquí, portNum y bitValue no son los mismos que port y pin para el SCU. Son otros parámetros que tienen la forma GPIOportNum[bitValue].

Registro de configuración de dirección de GPIO

Configuración de dirección de pines para LED1 y TEC1

Diodo LED: LED1 <---> P2_10, GPIO0[14], FUNC0

El LED1 corresponde a GPIO0[14], se configurará como salida (1) mediante registro GPIO_PORT0_DIR:

Dirección del registro GPIO_PORT0_DIR =
= GPIO_BASE + GPIO_PORT0_B_OFFSET + GPIO_PORT0_DIR_OFFSET = 0x400F4000 + 0x0 + 0x2000

Valor de configuración a guardar en esa dirección = (1 << 14) = 0x00004000

Usando LPCopen:

Chip_GPIO_SetDir( LPC_GPIO_PORT, 0, (1<<14), 1 );

Configuración de dirección de pines para LED1 y TEC1

Pulsador: | TEC1 <---> P1_0, | GPIO0[4], | FUNC0

TEC1 corresponde a GPIO0[4], se configurará como entrada (0) mediante registro GPIO_PORT0_DIR:

Dirección del registro GPIO_PORT0_DIR =
= GPIO_BASE + GPIO_PORT0_B_OFFSET + GPIO_PORT0_DIR_OFFSET = 0x400F4000 + 0x0 + 0x2000

Valor de configuración a guardar en esa dirección: ~(1 << 4)

Usando LPCopen:

Chip_GPIO_SetDir( LPC_GPIO_PORT, 0, (1<<4), 0 );

Para leer y escribir valores de un pin se utilizan las funciones:

void Chip_GPIO_SetPinState(
LPC_GPIO_T *pGPIO,
uint8_t port,
uint8_t pin,
bool setting
);

bool Chip_GPIO_GetPinState( LPC_GPIO_T *pGPIO,
uint8_t port,
uint8_t pin
);

Para más información referirse al capítulo 19 del manual de usuario del LPC4337

Funciones LPCOpen de GPIO para leer y escribir pines

Hasta aquí tenemos configurados ambos pines LED1 y TEC1 como salida y entrada, respectivamente, ya sea escribiendo registros, o bien, utilizando la biblioteca LPCopen.

Solo nos resta hacer un pequeño programa que lea el valor de TEC1 y lo refleje en LED1, que usando LPCopen es...

## Ejemplo Pulsador ---> LED

#include <chip.h>

#define OUTPUT | 1

#define INPUT | 0

#define ON | 1

#define OFF | 0

int main( void )
{
// Diodo LED: LED1 <---> P2_10, GPIO0[14] ----------------------------------Chip_SCU_PinMux( 2, 10, SCU_MODE_INACT, SCU_MODE_FUNC0 ); Chip_GPIO_SetDir( LPC_GPIO_PORT, 0, (1<<14), OUTPUT ); Chip_GPIO_SetPinState( LPC_GPIO_PORT, 0, 14, OFF );

// Pulsador: TEC1 <---> P1_0, GPIO0[4] -------------------------------------
Chip_SCU_PinMux( 1, 0, SCU_MODE_INACT | SCU_MODE_INBUFF_EN, SCU_MODE_FUNC0 );
Chip_GPIO_SetDir( LPC_GPIO_PORT, 0, (1<<4), INPUT );

while( 1 ) {
// !(TEC1) --> LED1
// Negado (!) porque el pulsador esta en 1 por defecto y al presionar da 0 uint8_t value = Chip_GPIO_GetPinState( LPC_GPIO_PORT, 0, 4 ); Chip_GPIO_SetPinState( LPC_GPIO_PORT, 0, 14, !value );
}
return 0;
}

## Ejemplo Pulsador ---> LED

- Manual de usuario del microcontrolador NXP LPC4337.
- Archivos de LPCOpen.
- Web del proyecto CIAA.

## Bibliografía

# Consultas:

ericpernia@gmail.com

# ¡Muchas gracias!

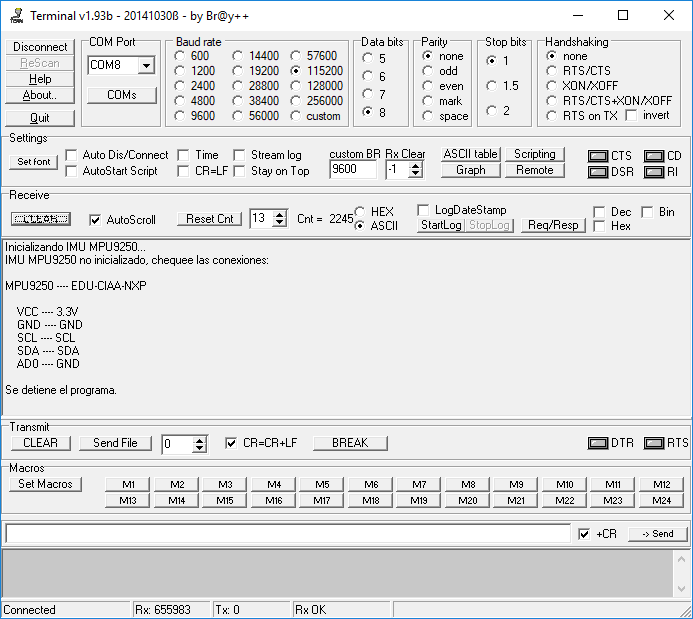
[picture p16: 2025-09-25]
firmware_v3/test/test_l298n/sapi/i2c/IMUs/mpu9250/Serial Terminal - MPU9250 not detected.PNG

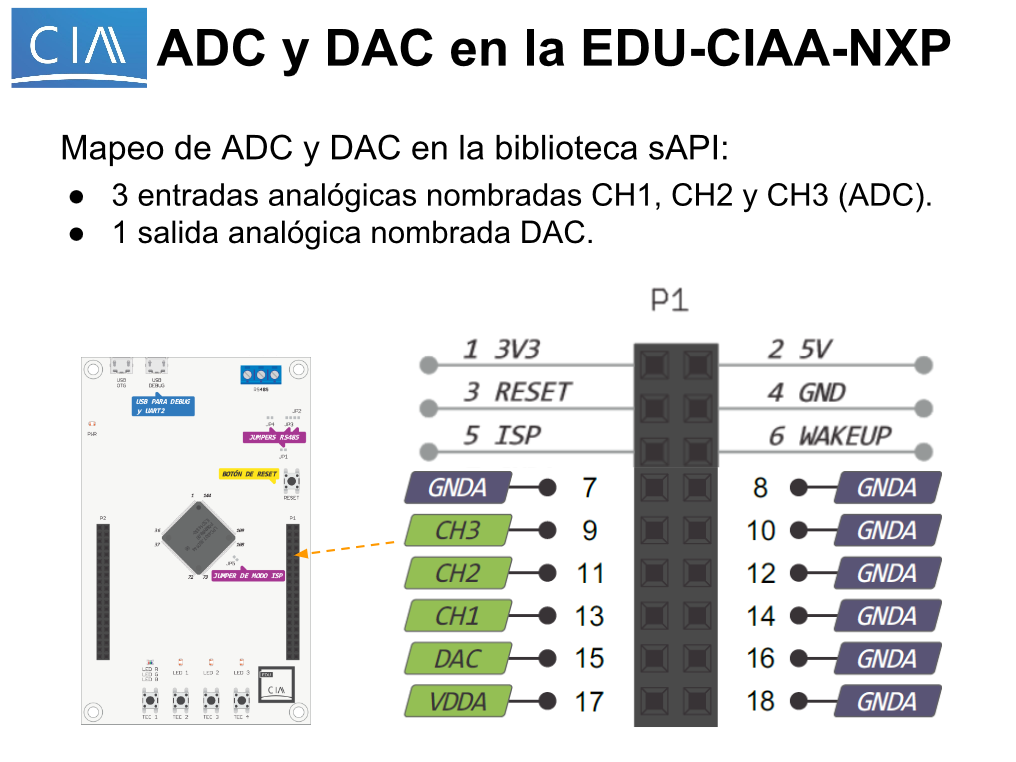
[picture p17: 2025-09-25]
firmware_v3/test/test_l298n/sapi/adc_dac/adc_dac_pins.png

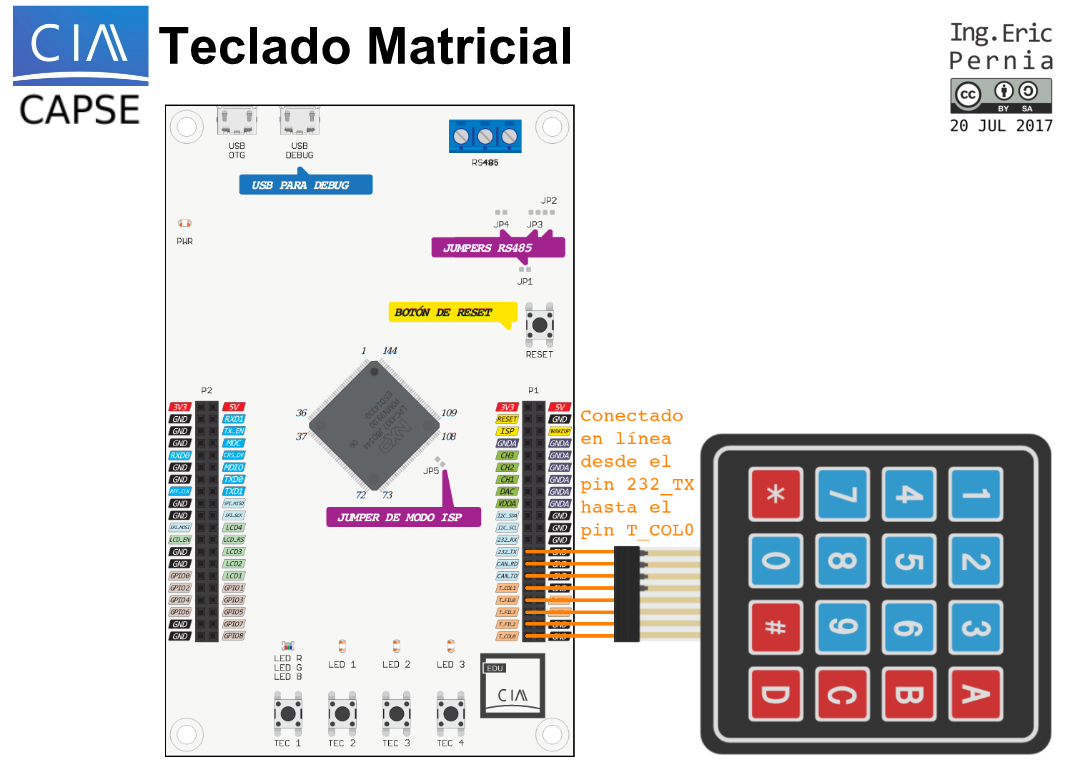
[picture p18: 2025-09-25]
firmware_v3/test/test_l298n/sapi/keypad_7segment/Keypad - EDU-CIAA-NXP.png

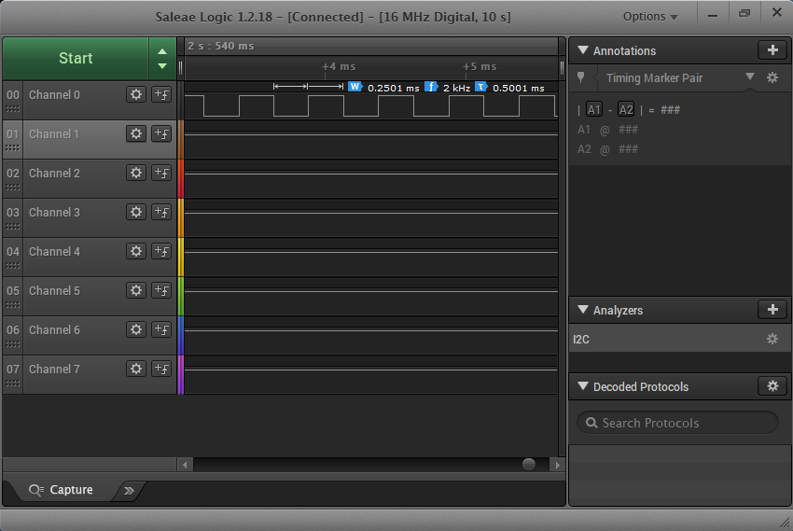
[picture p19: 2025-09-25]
firmware_v3/test/test_l298n/lpc_open/timer_250ms_pulse/250msSignal.png

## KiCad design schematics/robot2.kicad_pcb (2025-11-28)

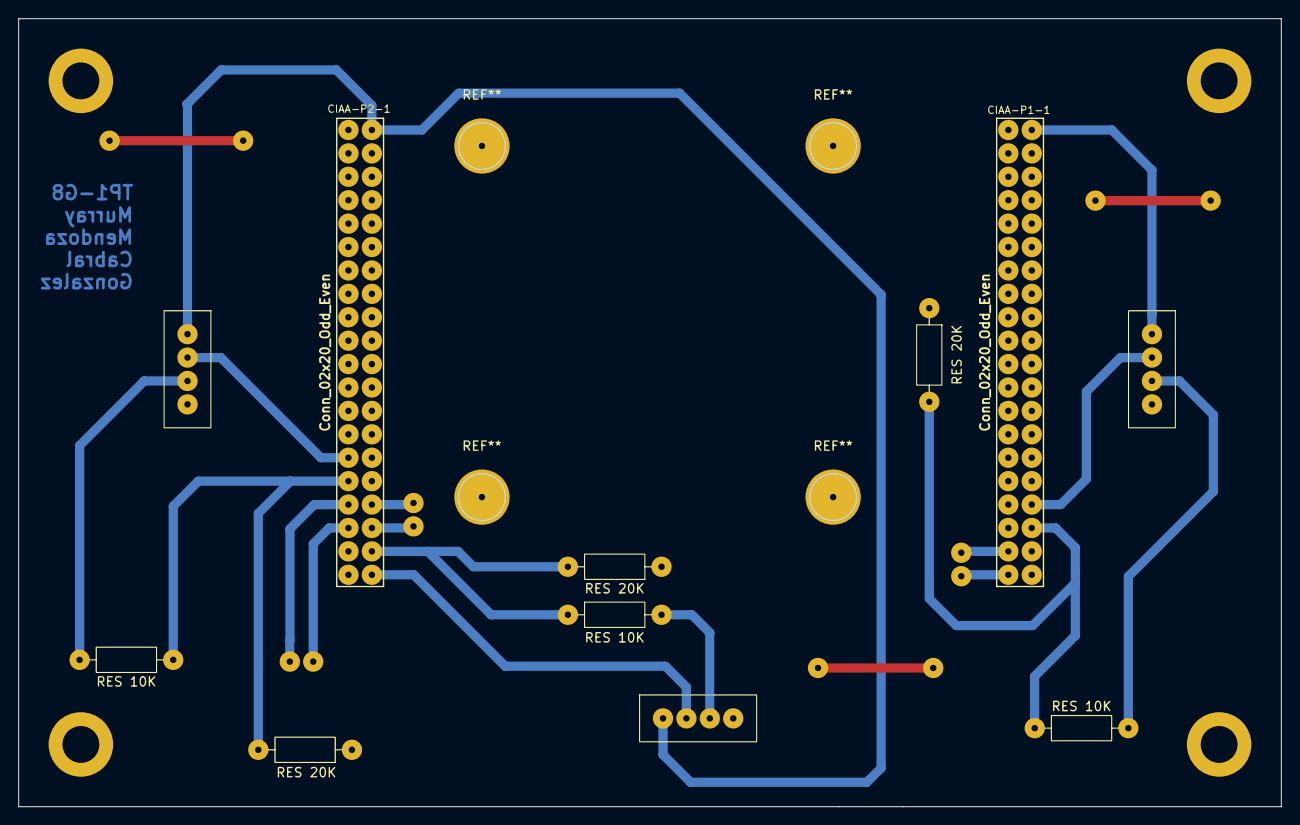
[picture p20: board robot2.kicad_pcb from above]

Board: 2 copper layers, 137.0 x 85.5 mm, 11 parts (0 on the bottom side), 12 nets.

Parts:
CIAA-P1-1, CIAA-P2-1: Conn_02x20_Odd_Even; PIN_ARRAY_20X2
HC-SR04-1, HC-SR04-2, HC-SR04-3: HC-SR04
R2, R5: 20K; R_Axial_DIN0207_L6.3mm_D2.5mm_P10.16mm_Horizontal
RES 10K, RES 10K#2, RES 10K#3: 10K; R_Axial_DIN0207_L6.3mm_D2.5mm_P10.16mm_Horizontal
RES 20K: 20K; R_Axial_DIN0207_L6.3mm_D2.5mm_P10.16mm_Horizontal

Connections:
5VL: CIAA-P2-1.2 (5V), HC-SR04-1.1 (Vcc), HC-SR04-2.1 (Vcc)
5VR: CIAA-P1-1.2 (5V), HC-SR04-3.1 (Vcc)
GND: CIAA-P1-1.4 (GND), CIAA-P1-1.7 (GNDA), CIAA-P2-1.11 (GND), HC-SR04-1.4 (GND), HC-SR04-2.4 (GND), HC-SR04-3.4 (GND), R2.1, R5.1, RES 20K.1
GPIO0: CIAA-P2-1.29 (GPIO0), HC-SR04-1.2 (Trigger)
GPIO2: CIAA-P2-1.31 (GPIO2), R5.2, RES 10K#2.1
GPIO7: CIAA-P2-1.38 (GPIO7), RES 10K.1, RES 20K.2
GPIO8: CIAA-P2-1.40 (GPIO8), HC-SR04-2.2 (Trigger)
unnamed: HC-SR04-1.3 (Echo), RES 10K#2.2
unnamed: HC-SR04-2.3 (Echo), RES 10K.2
unnamed: HC-SR04-3.3 (Echo), RES 10K#3.2
TCOL2: CIAA-P1-1.34 (TCOL2), HC-SR04-3.2 (Trigger)
TFIL1: CIAA-P1-1.36 (TFIL1), R2.2, RES 10K#3.1

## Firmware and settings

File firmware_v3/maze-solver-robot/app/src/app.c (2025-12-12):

// app/src/app.c

#include "sapi.h"
#include "wall_follower.h"
#include "../../drivers/inc/hc_sr04.h"
#include "../../drivers/inc/l298n.h"
#include "../../drivers/inc/robot_pins.h"

#define TEST_MODE 0  // 0=normal, 1=sensor, 2=motores
// #define SPEED_LEFT 115
// #define SPEED_RIGHT 110

#define SPEED_LEFT 115
#define SPEED_RIGHT 135
#define SPEED_PULSE 220
#define SPEED_TURN_SLOW 120
#define SPEED_TURN_FAST 200


int main(void) {
    boardConfig();
    uartConfig(UART_USB, 115200);

    // Inicialización de sensores y motores (comun a todos los modos)
    hc_sr04_init(SR04_01_ECHO_GPIO, SR04_01_TRIG_GPIO);  // Derecha
    hc_sr04_init(SR04_02_ECHO_GPIO, SR04_02_TRIG_GPIO);  // Central
    hc_sr04_init(SR04_03_ECHO_GPIO, SR04_03_TRIG_GPIO);  // Izquierda

    l298n_init();
   
    delay(1000);

#if TEST_MODE == 1
    printf("Test 3 sensores HC-SR04 simultáneo\r\n");

    while(TRUE) { 
        uint32_t dist_right = hc_sr04_distance_cm_right() / 100;
        delay(50); // pequeña separación entre pulsos para evitar interferencias

        uint32_t dist_front = hc_sr04_distance_cm_front() / 100;
        delay(50);

        uint32_t dist_left  = hc_sr04_distance_cm_left() / 100;

        printf("Front: %lu cm | Right: %lu cm | Left: %lu cm\r\n",
               dist_front, dist_right, dist_left);

        delay(200);
    }

#elif TEST_MODE == 2
    printf("Test motores L298N - modo sincronizado\r\n");

    while(TRUE) {
       
        avanzar();
        delay(2000);

        derecha();
        delay(350);

        avanzar();
        delay(2000);

        izquierda();
        delay(410);

        avanzar();
        delay(2000);

        giro_180();
        delay(800);

        printf("Stop\r\n");
        l298n_stop_all();       
        delay(1000);
    }

#else
    printf("Maze solver - modo 0 (wall follower)\r\n");
    wall_follower_init();
    //delay(5000);

    while(TRUE) {
      wall_follower_step();
    }
#endif
}

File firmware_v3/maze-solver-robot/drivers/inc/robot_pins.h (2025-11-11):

// drivers/inc/robot_pins.h
#ifndef ROBOT_PINS_H
#define ROBOT_PINS_H

// Pines HC-SR04
// Sensor derecha
#define SR04_01_TRIG_GPIO   GPIO0
#define SR04_01_ECHO_GPIO   GPIO2

// Sensor central
#define SR04_02_TRIG_GPIO   GPIO8
#define SR04_02_ECHO_GPIO   GPIO7

// Sensor izquierda
#define SR04_03_TRIG_GPIO   T_COL2
#define SR04_03_ECHO_GPIO   T_FIL1

// Pines L298N
#define L298_IN1 GPIO3
#define L298_IN2 GPIO5
#define L298_ENA PWM3 // T_COL0

#define L298_IN3 GPIO4
#define L298_IN4 GPIO6
#define L298_ENB PWM2 // T_FIL2
#endif // ROBOT_PINS_H

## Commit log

2025-09-28 added schematic v2
    [RobotLaberinto_KiCAD (1).kicad_sch]
2025-10-06 drivers hcsr04|l298n
2025-10-09 driver l298n reverse fix
    [app.c]
2025-10-16 added sensor pins
2025-10-19 stop front wall + new driver pins
2025-10-19 updt schematics
    [RobotLaberinto_KiCAD (1).kicad_sch, RobotLaberinto_KiCAD.kicad_sch]
2025-10-23 new motor pins
2025-10-23 schematic fixes
    [RobotLaberinto_KiCAD.kicad_sch]
2025-10-23 updated schematic
    [RobotLaberinto_KiCAD.kicad_sch]
2025-10-23 sensor calibration
2025-10-27 updated pcb
    [RobotLaberinto.kicad_pcb, RobotLaberinto.kicad_sch]
2025-10-29 updated motor control
2025-11-02 updt pins on ide and sch
    [RobotLaberinto.kicad_pcb, RobotLaberinto.kicad_sch]
2025-11-11 update PCB
    [RobotLaberinto.kicad_pcb, robot2.kicad_pcb, robot2.kicad_sch]
2025-11-17 updt pcb
    [robot2.kicad_pcb]
2025-11-18 updt pcb gnd
    [robot2.kicad_pcb]
2025-11-28 updt pcd
    [robot2.kicad_pcb]
2025-11-29 updated left motor orientation
